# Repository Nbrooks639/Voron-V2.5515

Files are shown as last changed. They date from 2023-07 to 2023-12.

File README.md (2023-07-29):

# V2.5515
Voron 2.4, 300 x 300, LDO Space gray frame, Orange/Purple, Octopus Max EZ w/ 5160RGB drivers, Canbus-BTT SB EBB 2209/RP 2040, Knomi SB Display

363856722_2440760692770372_4647321092019636357_n

363857884_1680409162472982_1060829333045094634_n

361948348_234994018873502_8382480590694910100_n

343570430_787175589434804_5643593835896998620_n



343931451_183420141285762_4473621401464647481_n

343491207_1399443794241117_2238458214166925049_n

341813346_989108252077047_8027406171801002718_n

342358910_938312980950535_6202861604096017607_n

341593527_1207914936696617_4549566025600170048_n

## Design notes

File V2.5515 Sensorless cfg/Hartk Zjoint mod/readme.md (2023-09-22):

# Voron 2.4 GE5C Z joint  

##

### BOM
Screws

Size | Qty
--- | ---
M3x16 or M3x20 SHCS | 16	
M5x20 | 4
GE5C Bearing | 4
M5x1mm spacer | 4
If using Halleffect 6x3 magnet | 1 

#### Notes about IGUS bearings

You can replace the GE5C bearings with IGUS models. There are two IGUS spherical bearings types: the `KGLM` and `EGLM` series. The EGLM are compatible with the files found in the `Z_Joints` folder, the KGLM require the files located in `Z_Joints/Phalanx`.

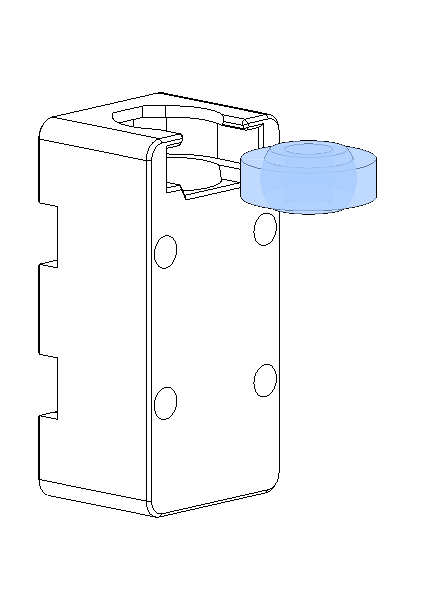
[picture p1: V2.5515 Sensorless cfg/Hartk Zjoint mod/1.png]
 

First just insert GE5C bearing , it should just pop in.

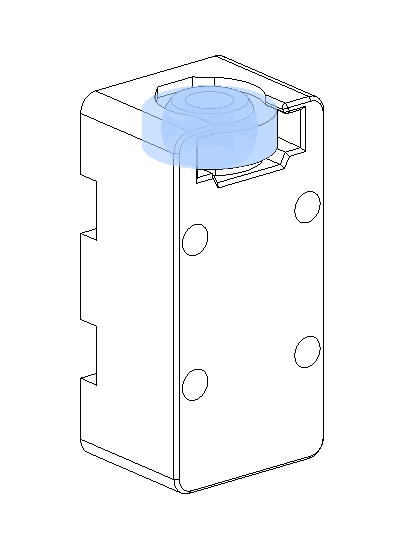
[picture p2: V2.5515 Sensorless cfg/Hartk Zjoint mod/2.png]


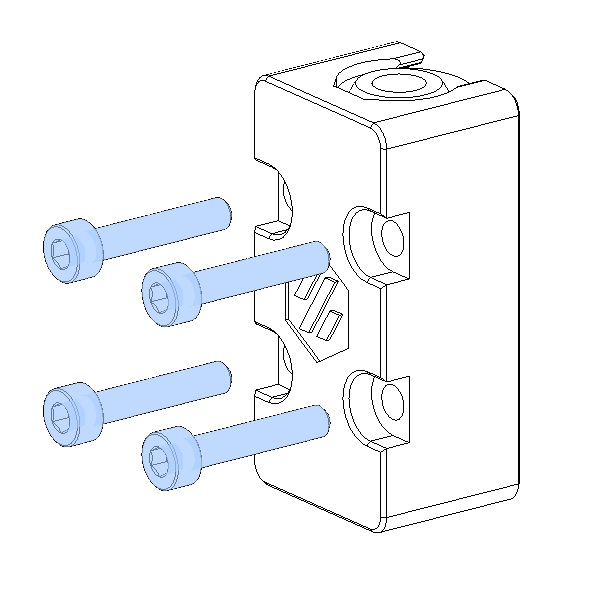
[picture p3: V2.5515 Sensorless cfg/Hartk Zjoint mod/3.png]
 

Now if you are using the "No Endstops" version you need 4 M3x16 screws per Z-joint, if you are using the endstop/halleffect version then you need 4 M3x20 per Z-joint.

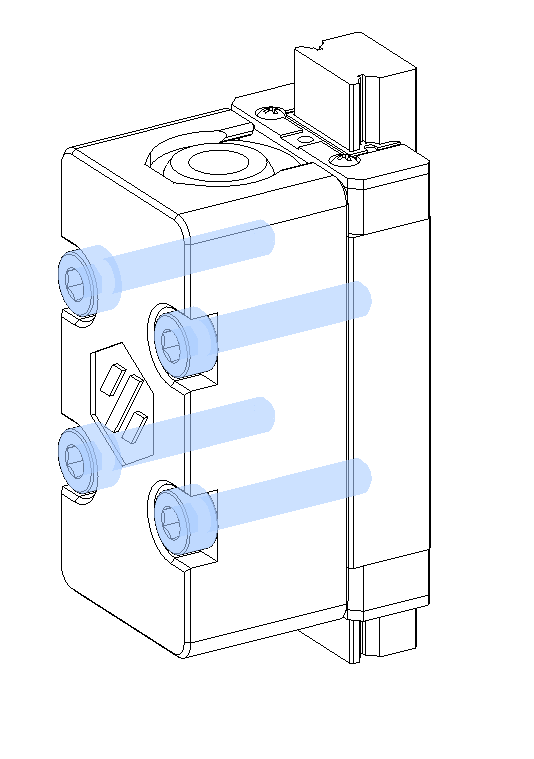
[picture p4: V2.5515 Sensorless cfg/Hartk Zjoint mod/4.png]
 

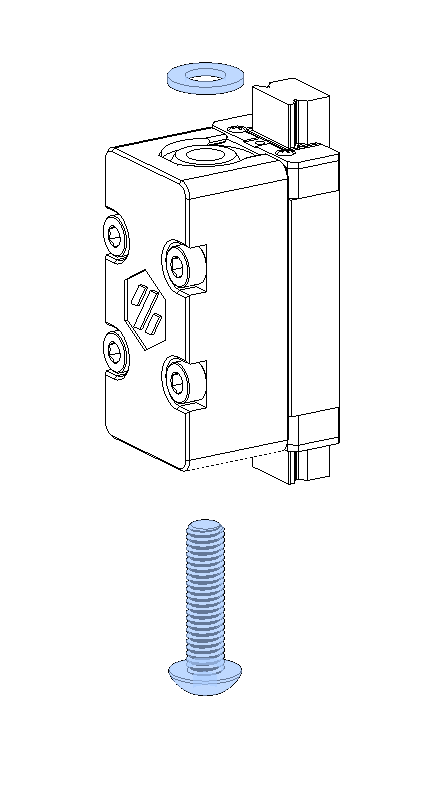
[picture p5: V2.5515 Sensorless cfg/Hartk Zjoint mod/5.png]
 

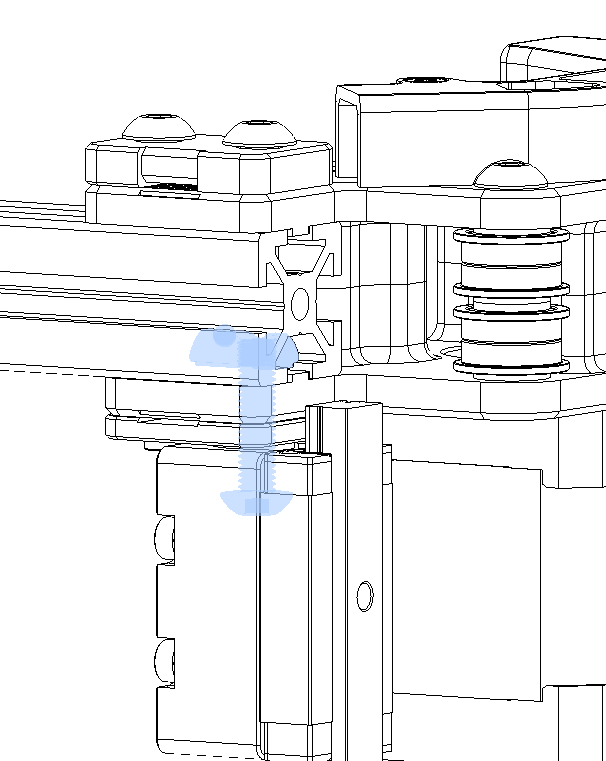
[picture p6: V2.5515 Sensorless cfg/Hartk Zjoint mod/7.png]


Use an M5x20 BHCS and 1 M5x1mm washer and screw it into the gantry using a roll-in T-nut.

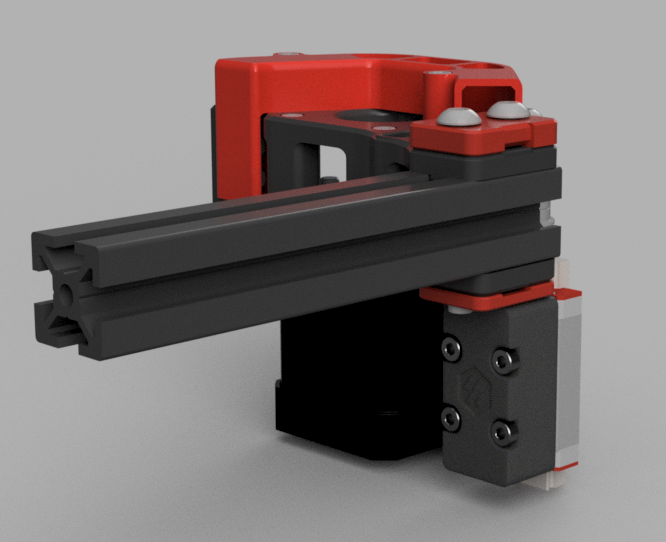
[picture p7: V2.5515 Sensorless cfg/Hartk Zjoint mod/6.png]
 

This is how it should be assembled when all done.

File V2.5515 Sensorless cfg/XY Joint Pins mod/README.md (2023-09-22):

## This has been updated for V2.4r2 and Trident 

This mod is for the V2/Trident, it involves printing new AB drive frames, new XY Joints, new Front Tensioners, and new Z idlers

The pins have replaced m5 screws, at any location where the screw acts like a shaft, holding bearings, pulleys or idlers. This allows for smoother rotation and stops the possibility of motion parts being caught in threads. This work was done by everyone, thanks to ABS plastic and voron printers for the fast iteration, @doomweasel? they fall out yet?

To complete this mod the following files will need to be reprinted 

**A and B drive units**

 - a_drive_frame_lower_pinned.stl 
 - a_drive_frame_upper_pinned.stl 
 - b_drive_frame_lower_pinned.stl 
 - b_drive_frame_upper_pinned.stl

**Front Idlers**
- [a]_a_tensioner_pinned.stl
- [a]_b_tensioner_pinned.stl

**XY Joints**
<<<<<<< Updated upstream:printer_mods/hartk1213/Voron2.4_Trident_Pins_Mod/README.md
- MGN12_xy_joint_left_upper_pinned.stl
- MGN12_xy_joint_left_lower_pinned.stl
- MGN12_xy_joint_right_upper_pinned.stl
- MGN12_xy_joint_right_lower_pinned.stl
=======
- xy_joint_left_upper_pinned.stl
- xy_joint_left_lower_pinned.stl
- xy_joint_right_upper_pinned.stl
- xy_joint_right_lower_pinned.stl
>>>>>>> Stashed changes:printer_mods/hartk1213/Voron2.4_Pins_Mod/README.md

**Z Idlers FOR V2**
either one of these based on if you are using 6mm or 9mm belt
- [a]_z_tensioner_x4_6mm_pinned.stl
- [a]_z_tensioner_x4_9mm_pinned.stl

here is what the XY Joint will look like

<<<<<<< Updated upstream:printer_mods/hartk1213/Voron2.4_Trident_Pins_Mod/README.md
XY Joint
XY Joint
=======
XY Joint 

There is a new file for the A Drive to go along with [Arkeets MGN12](https://github.com/VoronDesign/VoronUsers/tree/master/printer_mods/arkeet/mgn12) mod that has the X endstop on the toolhead 
and that is moving the Y endstop to the A drive, this is an optional mod 
this requires a 2pin jst to be soldered to the switch, 
the best way i have done it is to solder the wires to the jst first, then install it with a dab of super glue , then solder the wires to the omron switch 

- a_drive_frame_upper_with_jst_y_endstop_pinned

here are a few pics for reference

A Drive

A Drive With JST

Jst with Wires

you might need to bend the pins a little bit to get them to fit around the curve

JST with bent pins

>>>>>>> Stashed changes:printer_mods/hartk1213/Voron2.4_Pins_Mod/README.md

here is what the Z idler will look like
XY Joint

the following 5mm Pin hardware is what is needed as well 

**BOM**
```
[A-B] 
30mm (x2)
28mm (x2)

[X-Y Joints]
40mm (x4)

[X-Y Idlers]
43mm (x2)

[Z Idlers]
28mm (x4)
```

these can be purchased from here 

Smooth pins

[https://www.aliexpress.com/item/1739093502.html](https://www.aliexpress.com/item/1739093502.html "https://www.aliexpress.com/item/1739093502.html")

Misumi Part Numbers 

|Part NO.  |Qty  |
|--|--|
| SFR5-30 | 2 |
| SFR5-43 | 2 |
| SFR5-40 | 4 |
| SFR5-28 | 6 |

The following users are the main contributors to this mod

@RoboDave 

@DeepFriedHeroin 

@Hartk 

@DOOMweasel 

@Eddie

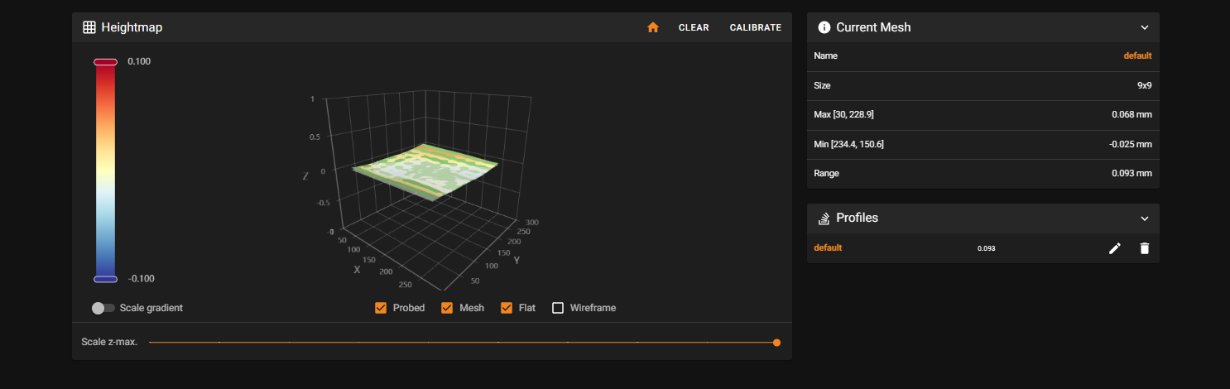
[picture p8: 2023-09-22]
V2.5515 Sensorless cfg/380547695_3519644291626807_1050257425948217919_n.png

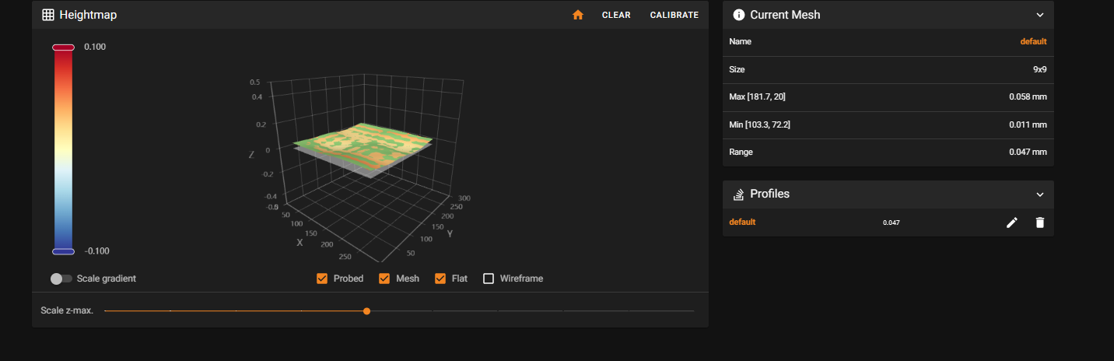
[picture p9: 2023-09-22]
V2.5515 Sensorless cfg/378262894_1677740269375349_278382346323434064_n.png

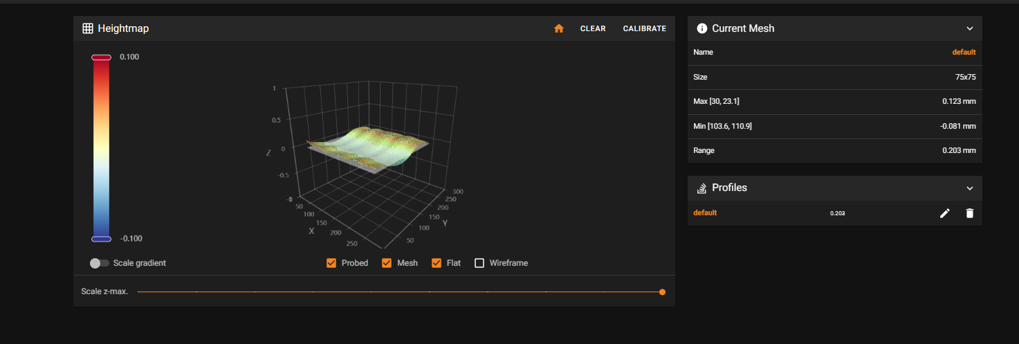
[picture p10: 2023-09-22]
V2.5515 Sensorless cfg/380653039_274774152050471_5273521995594914272_n.png

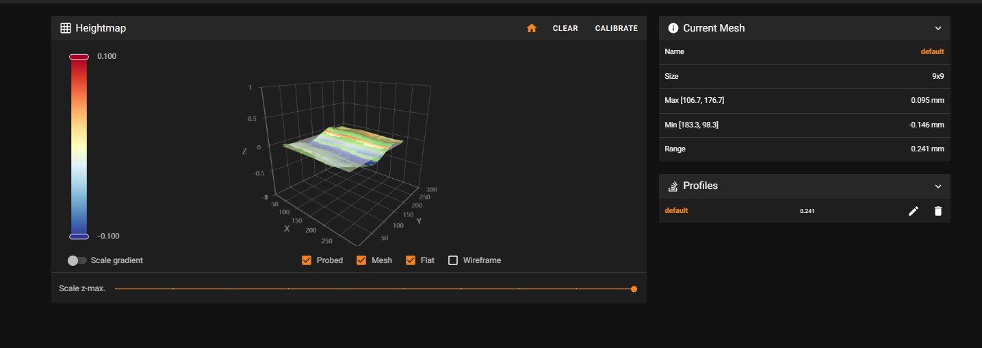
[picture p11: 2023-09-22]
V2.5515 Sensorless cfg/380691053_694317512748036_5317700327429051155_n.png

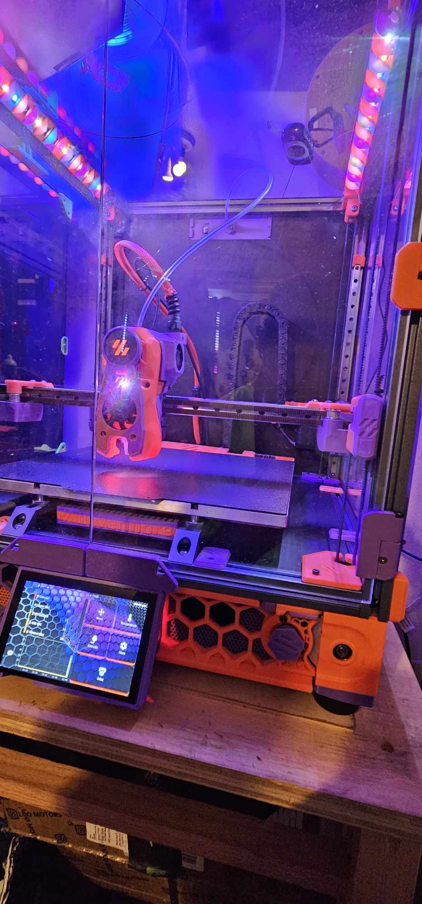
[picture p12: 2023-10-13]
V2.5515 Sensorless cfg/370083791_347611540946036_4173336297746885943_n.jpg

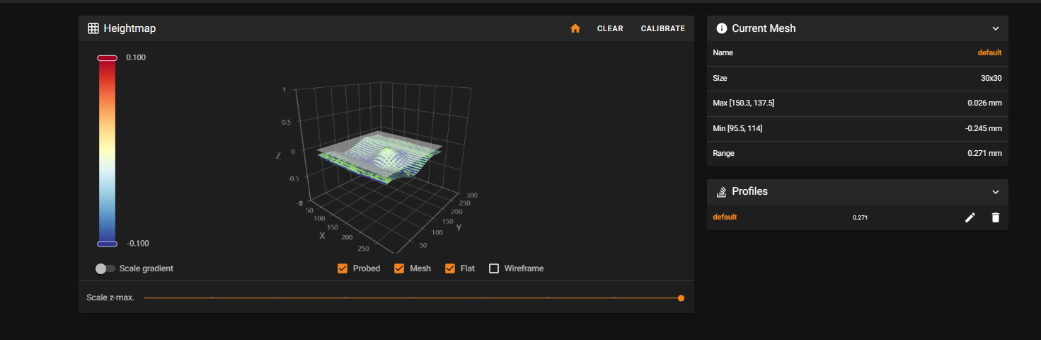
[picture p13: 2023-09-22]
V2.5515 Sensorless cfg/380662375_191119637329930_1164484691874327763_n.png

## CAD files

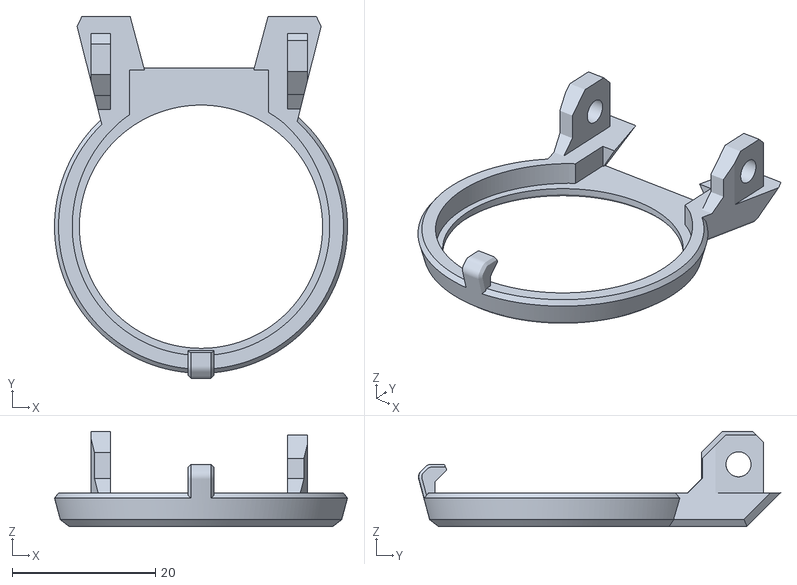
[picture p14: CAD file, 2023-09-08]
BTT Rapido UHF KENNY MOD/Kenny 2 Mod_ Knomi Display Hoody V1_1.stl
41.0 x 50.6 x 13.3

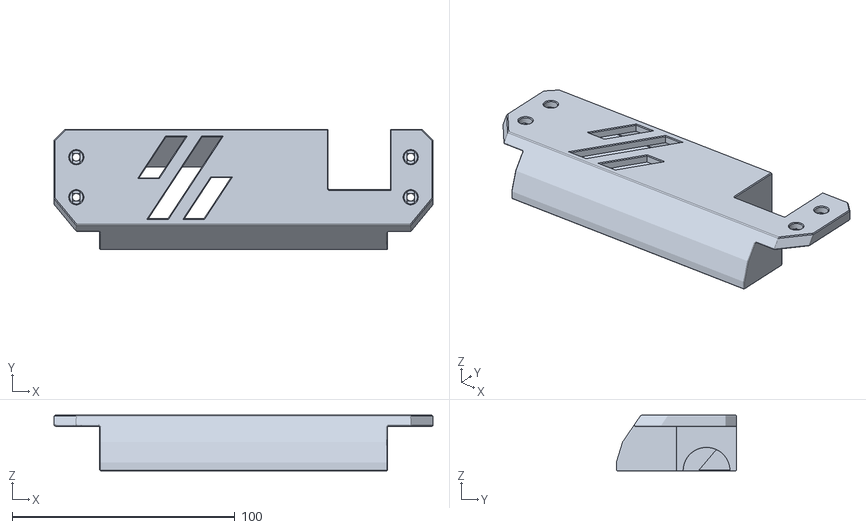
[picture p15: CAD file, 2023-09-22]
V2.5515 Sensorless cfg/Hartk Zjoint mod/Z_ChainCableCover.stl
170.0 x 54.0 x 25.0

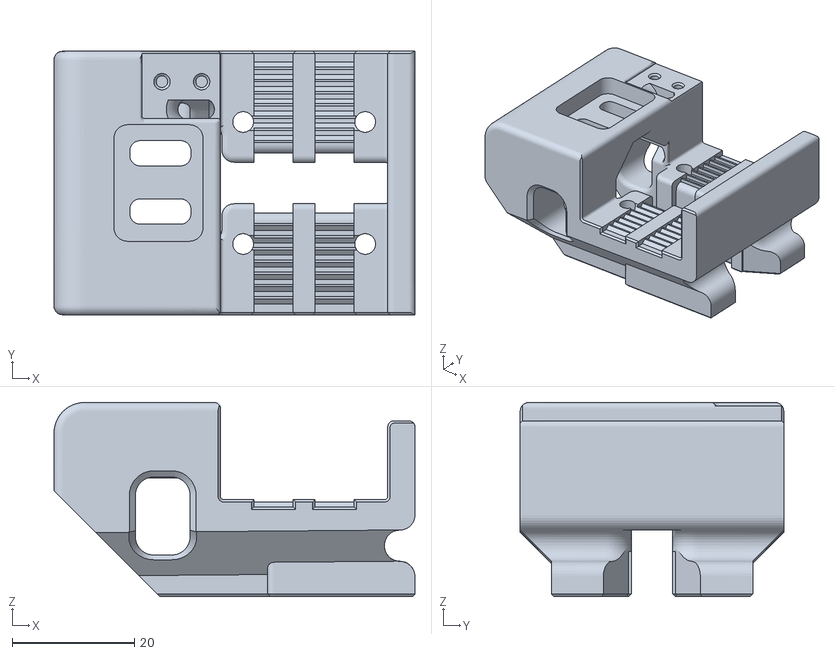
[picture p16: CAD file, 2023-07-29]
V2.5515 Sensorless cfg/Rapid Burner Rapido, Beacon/MGN12_X_Carriage.stl
59.2 x 43.2 x 31.8

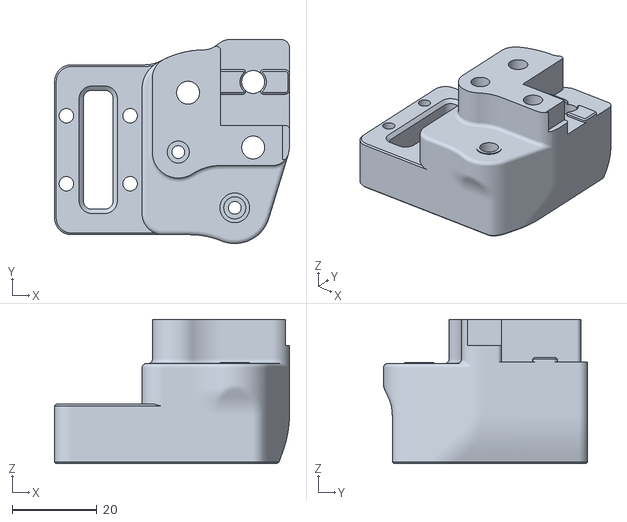
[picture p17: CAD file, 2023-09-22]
V2.5515 Sensorless cfg/XY Joint Pins mod/MGN12_xy_joint_left_lower_pinned.stl
55.3 x 48.0 x 34.0

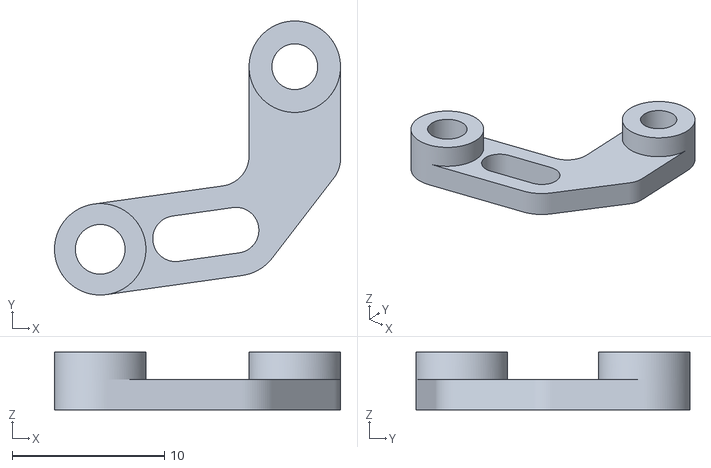
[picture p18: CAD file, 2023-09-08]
BTT Rapido UHF KENNY MOD/[a]_pcb_spacer.stl
18.8 x 18.0 x 3.80

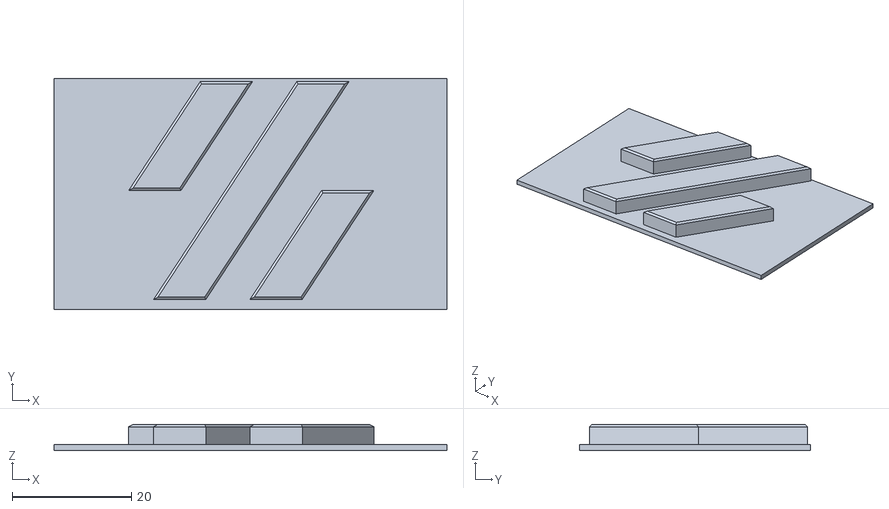
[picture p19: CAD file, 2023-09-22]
V2.5515 Sensorless cfg/Hartk Zjoint mod/LED_Diffuser.stl
65.9 x 38.7 x 4.40

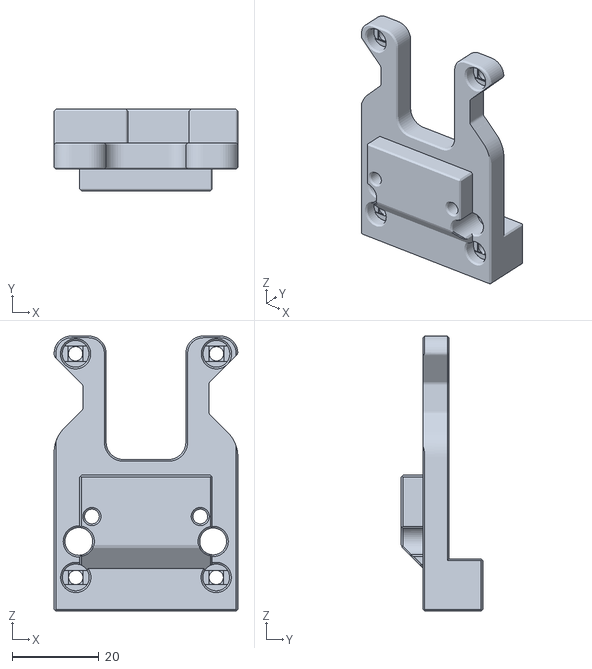
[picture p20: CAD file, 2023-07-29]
V2.5515 Sensorless cfg/Rapid Burner Rapido, Beacon/CW2_Adapter_Plate.stl
42.4 x 18.8 x 63.5

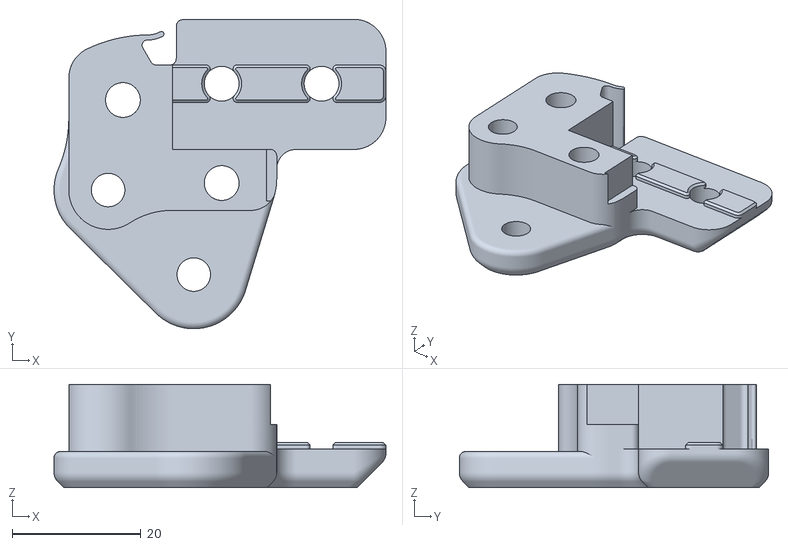
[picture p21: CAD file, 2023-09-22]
V2.5515 Sensorless cfg/XY Joint Pins mod/MGN12_xy_joint_right_upper_pinned.stl
51.5 x 48.0 x 16.0

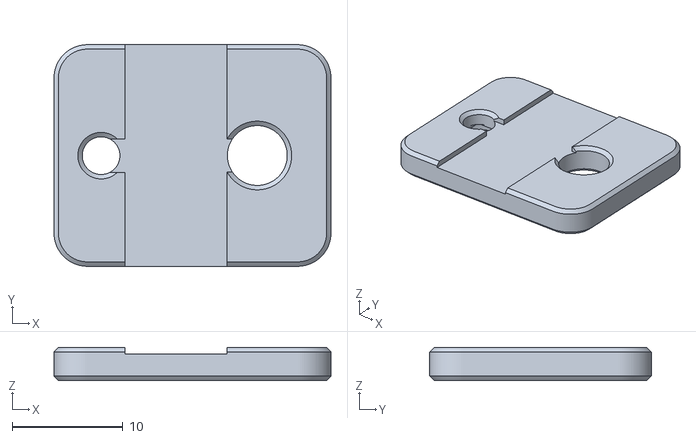
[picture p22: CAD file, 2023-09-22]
V2.5515 Sensorless cfg/Hartk Zjoint mod/[a]_z_belt_clamp_lower_x4.stl
25.0 x 20.0 x 3.00

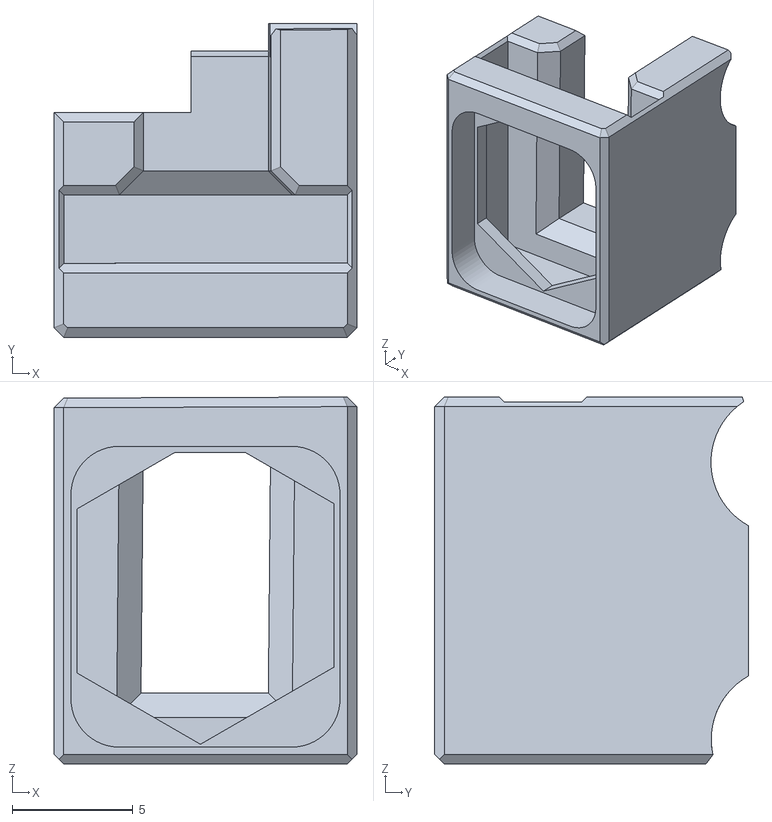
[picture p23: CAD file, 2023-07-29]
V2.5515 Sensorless cfg/Rapid Burner Rapido, Beacon/[o]_Carrier_RainbowBarf.stl
12.5 x 13.0 x 15.2

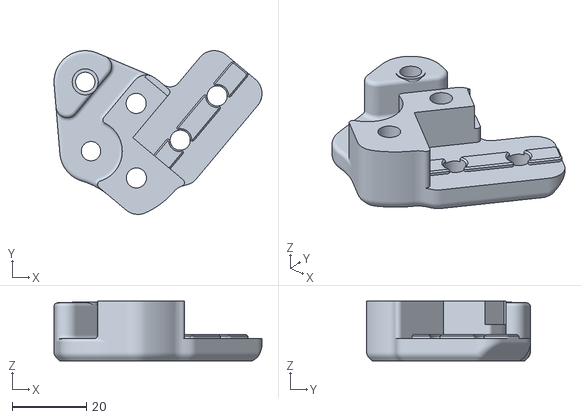
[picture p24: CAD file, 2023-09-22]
V2.5515 Sensorless cfg/XY Joint Pins mod/MGN12_xy_joint_left_upper_pinned.stl
55.9 x 44.0 x 16.0

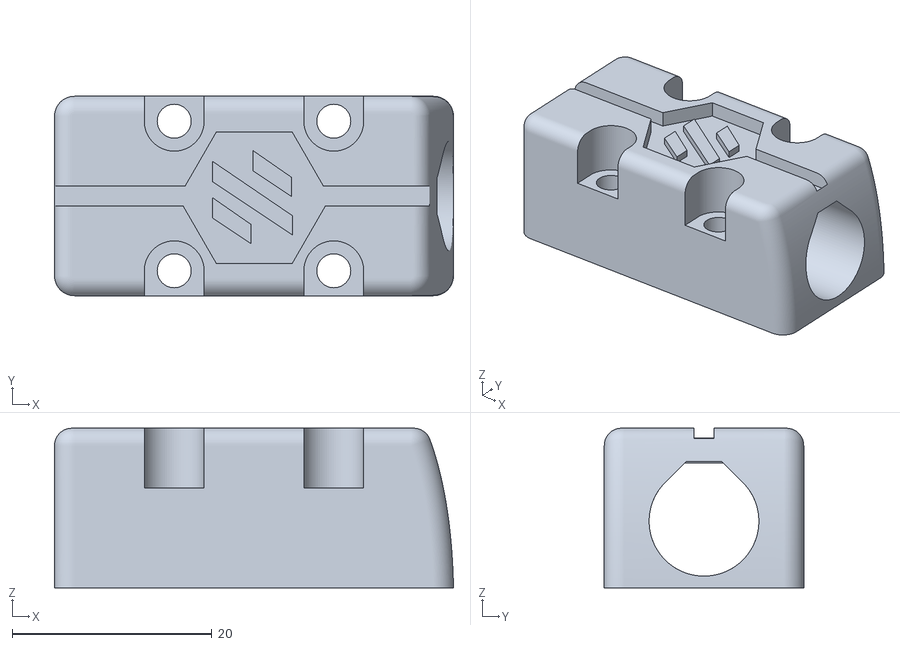
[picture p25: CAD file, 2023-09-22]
V2.5515 Sensorless cfg/Hartk Zjoint mod/z_joint_igus_kglm-05_x4.stl
40.0 x 20.0 x 16.0

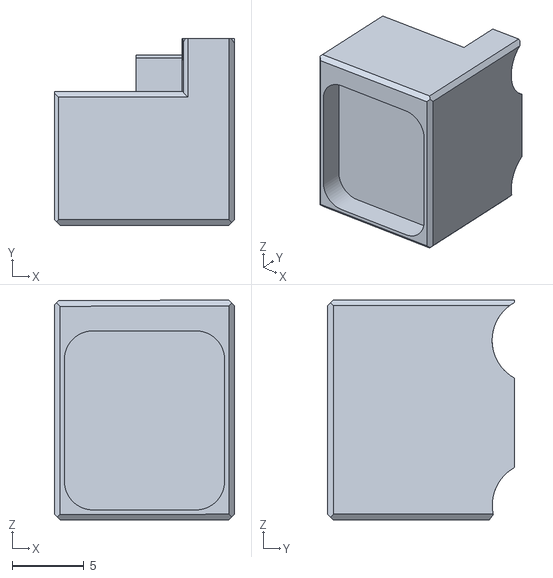
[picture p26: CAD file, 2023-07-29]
V2.5515 Sensorless cfg/Rapid Burner Rapido, Beacon/[a]_Carrier_Dummy.stl
12.5 x 13.0 x 15.3

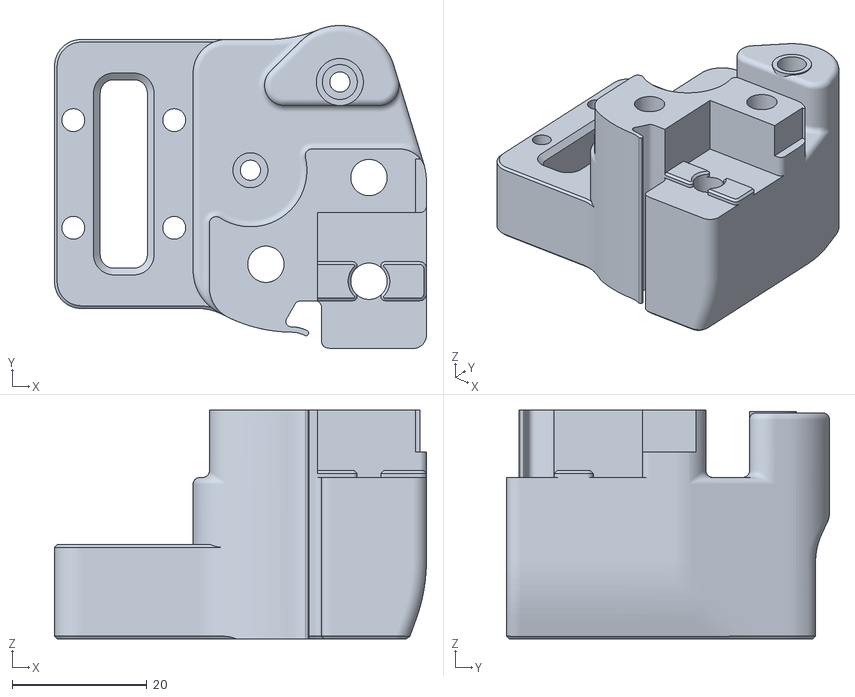
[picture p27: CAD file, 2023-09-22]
V2.5515 Sensorless cfg/XY Joint Pins mod/MGN12_xy_joint_right_lower_pinned.stl
55.3 x 48.0 x 34.0

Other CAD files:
V2.5515 Sensorless cfg/Hartk Zjoint mod/z_joint_ge5c_x4.stl
V2.5515 Sensorless cfg/Rapid Burner Rapido, Beacon/RapidoHF_Mount.stl
V2.5515 Sensorless cfg/Hartk Zjoint mod/z_joint_ge5c_y_endstop_x1.stl
V2.5515 Sensorless cfg/Rapid Burner Rapido, Beacon/[c]_Diffuser.stl
V2.5515 Sensorless cfg/Rapid Burner Rapido, Beacon/Cowl_NoProbe.stl
V2.5515 Sensorless cfg/Rapid Burner Rapido, Beacon/HE_Fan Mount_Neopixel.stl
V2.5515 Sensorless cfg/Rapid Burner Rapido, Beacon/LGX_Lite_Mount.stl
V2.5515 Sensorless cfg/Rapid Burner Rapido, Beacon/Probe_Bracket.stl
V2.5515 Sensorless cfg/Rapid Burner Rapido, Beacon/Probe_Support.stl

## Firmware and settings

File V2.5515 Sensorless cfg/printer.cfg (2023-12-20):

### FINe FINISH 3D  ########
#### V2.4-5515, 300mm, Octopus Max EZ, Can-Bus #############

[gcode_macro _CLIENT_VARIABLE]
variable_use_custom_pos   : True ; use custom park coordinates for x,y [True/False]
variable_custom_park_x    : 2.0   ; custom x position; value must be within your defined min and max of X
variable_custom_park_y    : 30.0   ; custom y position; value must be within your defined min and max of Y
variable_custom_park_dz   : 25.0   ; custom dz value; the value in mm to lift the nozzle when move to park position
variable_retract          : 8.0   ; the value to retract while PAUSE
variable_cancel_retract   : 18.0   ; the value to retract while CANCEL_PRINT
variable_speed_retract    : 30.0  ; retract speed in mm/s
variable_unretract        : 1.0   ; the value to unretract while RESUME
variable_speed_unretract  : 35.0  ; unretract speed in mm/s
variable_speed_hop        : 25.0  ; z move speed in mm/s
variable_speed_move       : 150.0 ; move speed in mm/s
variable_park_at_cancel   : True ; allow to move the toolhead to park while execute CANCEL_PRINT [True/False]
variable_park_at_cancel_x : 20.0  ; different park position during CANCEL_PRINT [None/Position as Float]; park_at_cancel must be True
variable_park_at_cancel_y : 296.0  ; different park position during CANCEL_PRINT [None/Position as Float]; park_at_cancel must be True
# !!! Caution [firmware_retraction] must be defined in the printer.cfg if you set use_fw_retract: True !!!
#variable_use_fw_retract  : False ; use fw_retraction instead of the manual version [True/False]
gcode:

[force_move]
enable_force_move: True

[include mainsail.cfg]
[include macros.cfg]
[include sensorless.cfg]
[include KAMP_Settings.cfg]
[include timelapse.cfg]
[include leds.cfg]
[include air_filter_timer.cfg]

[exclude_object]
[virtual_sdcard]
[pause_resume]
[display_status]

[save_variables]
filename: ~/printer_data/config/saved_variables.cfg

[respond]
default_type: command

[mcu]
serial: /dev/serial/by-id/usb-Klipper_stm32h723xx_310018001651303531313638-if00
restart_method: command
#canbus_uuid: b4a737e8f525

[mcu EBBCan]
#serial: /dev/serial/by-id/usb-Klipper_Klipper_firmware_12345-if00
canbus_uuid: a8036753aa32

[printer]
kinematics: corexy
max_velocity: 300 
max_accel: 8000           
max_z_velocity: 25          
max_z_accel: 350
max_accel_to_decel: 5500
square_corner_velocity: 10.0

[adxl345]
cs_pin: EBBCan:gpio1
spi_software_sclk_pin: EBBCan:gpio2
spi_software_mosi_pin: EBBCan:gpio0
spi_software_miso_pin: EBBCan:gpio3
axes_map: z,-y,x

[resonance_tester]
probe_points: 150, 130, 15
accel_chip: adxl345

# ############################################################################################
# ─────────██─██─██─██────███─███─███─████─████─███─████────███─███─███─███─███─█──█─████─███
# ──────────███───███─────█────█──█───█──█─█──█─█───█──█────█───█────█───█───█──██─█─█────█──
# ───────────█─────█──────███──█──███─████─████─███─████────███─███──█───█───█──█─██─█─██─███
# ──────────███────█────────█──█──█───█────█────█───█─█───────█─█────█───█───█──█──█─█──█───█
# ─────────██─██───█──────███──█──███─█────█────███─█─█─────███─███──█───█──███─█──█─████─███
# ############################################################################################

# Motor-1 (B)
[stepper_x]
step_pin: PC13
dir_pin: PC14
enable_pin: !PE6
rotation_distance: 40 
microsteps: 32
full_steps_per_rotation: 400 
endstop_pin: tmc5160_stepper_x: virtual_endstop
position_min: 0
position_endstop: 300
position_max: 300
homing_speed: 70
homing_retract_dist: 0
homing_positive_dir: true

[tmc5160 stepper_x] #RGB
cs_pin: PG14
spi_software_miso_pin: PE13
spi_software_mosi_pin: PE14
spi_software_sclk_pin: PE12
diag1_pin: ^!PF0
interpolate: True
driver_MULTISTEP_FILT: False
driver_SGT: -2  # -64 is most sensitive value, 63 is least sensitive
run_current: 0.9
sense_resistor: 0.050
stealthchop_threshold: 0

# Motor-2 (A)
[stepper_y]
step_pin: PE4
dir_pin: PE5
enable_pin: !PE3
rotation_distance: 40 
microsteps: 32
full_steps_per_rotation: 400
endstop_pin: tmc5160_stepper_y: virtual_endstop #PF2
position_min: 0
position_endstop: 300
position_max: 300
homing_speed: 70
homing_retract_dist: 0
homing_positive_dir: true

[tmc5160 stepper_y] #RGB
cs_pin: PG13
spi_software_miso_pin: PE13
spi_software_mosi_pin: PE14
spi_software_sclk_pin: PE12
diag1_pin: ^!PF2
interpolate: True
driver_MULTISTEP_FILT: False
driver_SGT: -2  # -64 is most sensitive value, 63 is least sensitive
run_current: 0.9
sense_resistor: 0.050
stealthchop_threshold: 0

# ###################################################################################################
# ─────────████────███─███─███─████─████─███─████────███─███─███─███─███─█──█─████─███
# ───────────██────█────█──█───█──█─█──█─█───█──█────█───█────█───█───█──██─█─█────█──
# ──────────██─────███──█──███─████─████─███─████────███─███──█───█───█──█─██─█─██─███
# ─────────██────────█──█──█───█────█────█───█─█───────█─█────█───█───█──█──█─█──█───█
# ─────────████────███──█──███─█────█────███─█─█─────███─███──█───█──███─█──█─████─███
# ###################################################################################################

# Motor-3 (FL)
[stepper_z]
step_pin: PD3
dir_pin: !PD2
enable_pin: !PD4
rotation_distance: 40
gear_ratio: 80:16
microsteps: 32
#full_steps_per_rotation: 200
endstop_pin: probe:z_virtual_endstop # use beacon as virtual endstop
position_max: 260
position_min: -5
homing_speed: 50
second_homing_speed: 5
homing_retract_dist: 0 # beacon needs this to be set to 0

[tmc5160 stepper_z] #RGB
# cs_pin: PG12
cs_pin: PD7
spi_software_miso_pin: PE13
spi_software_mosi_pin: PE14
spi_software_sclk_pin: PE12
driver_MULTISTEP_FILT: False
interpolate: True
run_current: 0.9
sense_resistor: 0.050
stealthchop_threshold: 999999

# Motor-4 (RL)
[stepper_z1]
step_pin: PB8
dir_pin: PB9
enable_pin: !PB7
rotation_distance: 40
gear_ratio: 80:16
microsteps: 32
#full_steps_per_rotation: 200

[tmc5160 stepper_z1] #RGB
cs_pin: PG11
spi_software_miso_pin: PE13
spi_software_mosi_pin: PE14
spi_software_sclk_pin: PE12
driver_MULTISTEP_FILT: False
interpolate: True
run_current: 0.9
sense_resistor: 0.050
stealthchop_threshold: 999999

# Motor-5 (RR)
[stepper_z2]
step_pin: PB5
dir_pin: !PB4
enable_pin: !PB6
rotation_distance: 40
gear_ratio: 80:16
microsteps: 32
#full_steps_per_rotation: 200

[tmc5160 stepper_z2] #RGB
cs_pin: PG10
spi_software_miso_pin: PE13
spi_software_mosi_pin: PE14
spi_software_sclk_pin: PE12
driver_MULTISTEP_FILT: False
interpolate: True
run_current: 0.9
sense_resistor: 0.050
stealthchop_threshold: 999999

# Motor-6 (FR)
[stepper_z3]
step_pin: PG15
dir_pin: PB3
enable_pin: !PD5
rotation_distance: 40
gear_ratio: 80:16
microsteps: 32
#full_steps_per_rotation: 200

[tmc5160 stepper_z3] #RGB
cs_pin: PG9
spi_software_miso_pin: PE13
spi_software_mosi_pin: PE14
spi_software_sclk_pin: PE12
driver_MULTISTEP_FILT: False
interpolate: True
run_current: 0.9
sense_resistor: 0.050
stealthchop_threshold: 999999

# ####################################################
# ─────────███─██─██─███─████─█─█─████──███─████──────
# ─────────█────███───█──█──█─█─█─█──██─█───█──█──────
# ─────────███───█────█──████─█─█─█──██─███─████──────
# ─────────█────███───█──█─█──█─█─█──██─█───█─█───────
# ─────────███─██─██──█──█─█──███─████──███─█─█───────
# ####################################################

[extruder]
step_pin: EBBCan:gpio18
dir_pin: EBBCan:gpio19
enable_pin: !EBBCan:gpio17
rotation_distance: 22.752
gear_ratio: 50:10
microsteps: 32
full_steps_per_rotation: 200
nozzle_diameter: 0.400
filament_diameter: 1.750
#instantaneous_corner_velocity: 1.5
heater_pin: EBBCan:gpio7
sensor_type: MAX31865
sensor_pin: EBBCan:gpio9
# smooth_time: .4
spi_software_sclk_pin: EBBCan:gpio10
spi_software_mosi_pin: EBBCan:gpio8
spi_software_miso_pin: EBBCan:gpio11
rtd_nominal_r: 1000
rtd_reference_r: 4300
rtd_num_of_wires: 2
#control: pid
#pid_Kp: 21.527
#pid_Ki: 1.063
#pid_Kd: 108.982
min_temp: 10
max_temp: 350
max_power: 1.0
min_extrude_temp: 180
max_extrude_cross_section: 5.0
max_extrude_only_distance: 100.0
pressure_advance: 0.05
pressure_advance_smooth_time: 0.04

[tmc2209 extruder]
uart_pin: EBBCan:gpio20
run_current: 0.550
stealthchop_threshold: 0

# [verify_heater extruder]
# hysteresis: 10
# check_gain_time: 40
# heating_gain: 2
# max_error: 500

# [firmware_retraction]
# retract_length: .7
# retract_speed: 30
# unretract_speed: 10

[gcode_arcs]
resolution: 0.1

# #############################################################
# ─────────████──███─████─────█──█─███─████─███─███─████──────
# ─────────█──██─█───█──██────█──█─█───█──█──█──█───█──█──────
# ─────────████──███─█──██────████─███─████──█──███─████──────
# ─────────█──██─█───█──██────█──█─█───█──█──█──█───█─█───────
# ─────────████──███─████─────█──█─███─█──█──█──███─█─█───────
# #############################################################
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

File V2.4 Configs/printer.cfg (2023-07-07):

 # Fine Finish 3D 300mm, V2.4 #5515 LDO Rev A/C kit From Fabreeko, Space gray frame, Orange & Purple Parts
 # Canbus setup SB2209, CNC Tap By Choaticlabs, Knomi Display, Octopus 1.1, Raspi 3B, 

[gcode_macro _CLIENT_VARIABLE]
variable_use_custom_pos   : True ; use custom park coordinates for x,y [True/False]
variable_custom_park_x    : 200.0   ; custom x position; value must be within your defined min and max of X
variable_custom_park_y    : 25.0   ; custom y position; value must be within your defined min and max of Y
variable_custom_park_dz   : 25.0   ; custom dz value; the value in mm to lift the nozzle when move to park position
variable_retract          : 1.0   ; the value to retract while PAUSE
variable_cancel_retract   : 7.0   ; the value to retract while CANCEL_PRINT
variable_speed_retract    : 35.0  ; retract speed in mm/s
variable_unretract        : 1.0   ; the value to unretract while RESUME
variable_speed_unretract  : 35.0  ; unretract speed in mm/s
variable_speed_hop        : 15.0  ; z move speed in mm/s
variable_speed_move       : 100.0 ; move speed in mm/s
variable_park_at_cancel   : True ; allow to move the toolhead to park while execute CANCEL_PRINT [True/False]
variable_park_at_cancel_x : 100.0  ; different park position during CANCEL_PRINT [None/Position as Float]; park_at_cancel must be True
variable_park_at_cancel_y : 280.0  ; different park position during CANCEL_PRINT [None/Position as Float]; park_at_cancel must be True
# !!! Caution [firmware_retraction] must be defined in the printer.cfg if you set use_fw_retract: True !!!
variable_use_fw_retract   : False ; use fw_retraction instead of the manual version [True/False]
#variable_idle_timeout     : 0     ; time in sec until idle_timeout kicks in. Value 0 means that no value will be set or restored
gcode:

[save_variables]
filename: ~/printer_data/config/saved_variables.cfg

[include macros.cfg]
[include mainsail.cfg]
[include stealthburner_led_effects_barf_fan.cfg]
[include timelapse.cfg]
[include air_filter_timer.cfg]
[include KAMP_Settings.cfg]
[exclude_object]
[virtual_sdcard]


[respond]
default_type: command

[mcu]
##--------------------------------------------------------------------
serial: /dev/serial/by-id/usb-Klipper_stm32f446xx_12003D000150335331383520-if00
restart_method: command
#canbus_uuid: 446b7d462f1b
##--------------------------------------------------------------------

[mcu EBBCan]
#serial: /dev/serial/by-id/usb-Klipper_Klipper_firmware_12345-if00
canbus_uuid: 7ac58ae2e407

[adxl345]
cs_pin: EBBCan: PB12
spi_software_sclk_pin: EBBCan: PB10
spi_software_mosi_pin: EBBCan: PB11
spi_software_miso_pin: EBBCan: PB2
axes_map: z,-y,x

[resonance_tester]
probe_points: 150, 150, 20
accel_chip: adxl345

[printer]
kinematics: corexy
max_velocity: 300  
max_accel: 8000             #Max 4000
max_z_velocity: 25          #Max 15 for 12V TMC Drivers, can increase for 24V
max_z_accel: 350
max_accel_to_decel: 3500
square_corner_velocity: 5.0

#####################################################################
#   X/Y Stepper Settings
#####################################################################

[stepper_x]
step_pin: PF13
dir_pin: PF12
enable_pin: !PF14
rotation_distance: 40
microsteps: 32
full_steps_per_rotation:400  #set to 200 for 1.8 degree stepper
endstop_pin: EBBCan:PB6
position_min: 0
position_endstop: 300
position_max: 300
homing_speed: 100   #Max 100
homing_retract_dist: 5
homing_positive_dir: true

[tmc2209 stepper_x]
uart_pin: PC4
interpolate: false
run_current: 0.9
sense_resistor: 0.110
stealthchop_threshold: 0

[stepper_y]
step_pin: PG0
dir_pin: PG1
enable_pin: !PF15
rotation_distance: 40
microsteps: 32
full_steps_per_rotation:400  #set to 200 for 1.8 degree stepper
endstop_pin: PG9
position_min: 0
position_endstop: 301
position_max: 301
homing_speed: 100  #Max 100
homing_retract_dist: 5
homing_positive_dir: true

[tmc2209 stepper_y]
uart_pin: PD11
interpolate: false
run_current: 0.9
sense_resistor: 0.110
stealthchop_threshold: 0
 
#####################################################################
#   Z Stepper Settings
#####################################################################

[stepper_z]
step_pin: PF11
dir_pin: !PG3
enable_pin: !PG5
rotation_distance: 40
gear_ratio: 80:16
microsteps: 32
endstop_pin: probe:z_virtual_endstop
#full_steps_per_rotation: 200
position_max: 260
position_min: -5
homing_speed: 8
second_homing_speed: 5
homing_retract_dist: 3

[tmc2209 stepper_z]
uart_pin: PC6
interpolate: false
run_current: 0.8
sense_resistor: 0.110
stealthchop_threshold: 999999

[stepper_z1]
step_pin: PG4
dir_pin: PC1
enable_pin: !PA0
rotation_distance: 40
gear_ratio: 80:16
microsteps: 32
#full_steps_per_rotation: 200

[tmc2209 stepper_z1]
uart_pin: PC7
interpolate: false
run_current: 0.8
sense_resistor: 0.110
stealthchop_threshold: 999999

[stepper_z2]
step_pin: PF9
dir_pin: !PF10
enable_pin: !PG2
rotation_distance: 40
gear_ratio: 80:16
microsteps: 32
#full_steps_per_rotation: 200

[tmc2209 stepper_z2]
uart_pin: PF2
interpolate: false
run_current: 0.8
sense_resistor: 0.110
stealthchop_threshold: 999999

[stepper_z3]
step_pin: PC13
dir_pin: PF0
enable_pin: !PF1
rotation_distance: 40
gear_ratio: 80:16
microsteps: 32
#full_steps_per_rotation: 200

[tmc2209 stepper_z3]
uart_pin: PE4
interpolate: false
run_current: 0.8
sense_resistor: 0.110
stealthchop_threshold: 999999


#####################################################################
#   Extruder
#####################################################################

[extruder]
step_pin: EBBCan: PD0
dir_pin: EBBCan: PD1
enable_pin: !EBBCan: PD2
rotation_distance: 22.6789511   #Bondtech 5mm Drive Gears
gear_ratio: 50:10               #BMG Gear Ratio
microsteps: 32
full_steps_per_rotation: 200    #200 for 1.8 degree, 400 for 0.9 degree
nozzle_diameter: 0.400
filament_diameter: 1.75
heater_pin: EBBCan: PB13
sensor_type: ATC Semitec 104NT-4-R025H42G
sensor_pin: EBBCan: PA3
min_temp: 10
max_temp: 300
max_power: 1.0
min_extrude_temp: 170
#control = pid
#pid_kp = 26.213
#pid_ki = 1.304
#pid_kd = 131.721
pressure_advance: 0.036
pressure_advance_smooth_time: 0.040
max_extrude_cross_section: 5

[tmc2209 extruder]
uart_pin: EBBCan: PA15
run_current: 0.6
stealthchop_threshold: 0

[firmware_retraction]
# retract_length: .8
# retract_speed: 35

# Enable arcs support
[gcode_arcs]
resolution: 1.0


#####################################################################
#   Bed Heater
#####################################################################


##  SSR Pin - HE1
##  Thermistor - TB
[heater_bed]
heater_pin: PA1
sensor_type: Generic 3950
sensor_pin: PF3
max_power: 0.9
min_temp: 0
max_temp: 120
#control: pid
#pid_kp: 58.437
#pid_ki: 2.347
#pid_kd: 363.769


#####################################################################
#   Probe
#####################################################################

[probe]
pin: EBBCan:PB5
x_offset: 0
y_offset: 0
#z_offset: -2
speed: 10
lift_speed: 25
samples: 1
samples_result: median
sample_retract_dist: 3
samples_tolerance: 0.006
samples_tolerance_retries: 3
activate_gcode:
    {% set PROBE_TEMP = 150 %}
    {% set MAX_TEMP = PROBE_TEMP + 5 %}
    {% set ACTUAL_TEMP = printer.extruder.temperature %}
    {% set TARGET_TEMP = printer.extruder.target %}

    {% if TARGET_TEMP > PROBE_TEMP %}
        { action_respond_info('Extruder temperature target of %.1fC is too high, lowering to %.1fC' % (TARGET_TEMP, PROBE_TEMP)) }
        M109 S{ PROBE_TEMP }
    {% else %}
        # Temperature target is already low enough, but nozzle may still be too hot.
        {% if ACTUAL_TEMP > MAX_TEMP %}
            { action_respond_info('Extruder temperature %.1fC is still too high, waiting until below %.1fC' % (ACTUAL_TEMP, MAX_TEMP)) }
            TEMPERATURE_WAIT SENSOR=extruder MAXIMUM={ MAX_TEMP }
        {% endif %}
    {% endif %}

[safe_z_home]
home_xy_position: 150, 150
speed: 200
z_hop: 10
z_hop_speed: 10

[quad_gantry_level]
gantry_corners:
  -60,-10
  360,370
points:
  50,25
  50,225
  250,225
  250,25
  
speed: 200
horizontal_move_z: 10
retries: 5
retry_tolerance: 0.0075
max_adjust: 10

[bed_mesh]
fade_start: 0.6
fade_end: 10.0
speed: 200
horizontal_move_z: 3
mesh_min: 25,25
mesh_max: 280,280
probe_count: 5,5
algorithm: bicubic
bicubic_tension: 0.2

#####################################################################
#   Fan Control
#####################################################################
# [heater_fan EBB_Fan]
# pin: EBBCan: PB14
# # tachometer_pin: EBBCan: PB15
# # tachometer_ppr: 1

[heater_fan Electronics1]
pin: PD12
max_power: 1.0
shutdown_speed: 0.0
kick_start_time: 0.3
heater: heater_bed
heater_temp: 20
fan_speed: 0.9

[fan]
# Parts Cooling Fan #
pin: EBBCan: PA1
kick_start_time: 0.5
off_below: 0.10

[heater_fan Hotend]
pin: EBBCan: PA0
max_power: 1.0
kick_start_time: 0.5
heater: extruder
heater_temp: 65.0
fan_speed: 0.7
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

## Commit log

2023-05-29 Update and rename stealthburner_leds.cfg to rgb.cfg
    [rgb.cfg, stealthburner_leds.cfg]
2023-07-18 Create sensorless.cfg
    RGB EZ 5160 Drivers
    [sensorless.cfg]
